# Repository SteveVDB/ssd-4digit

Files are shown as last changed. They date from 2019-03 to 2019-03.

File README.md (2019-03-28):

# DIY seven-segment display

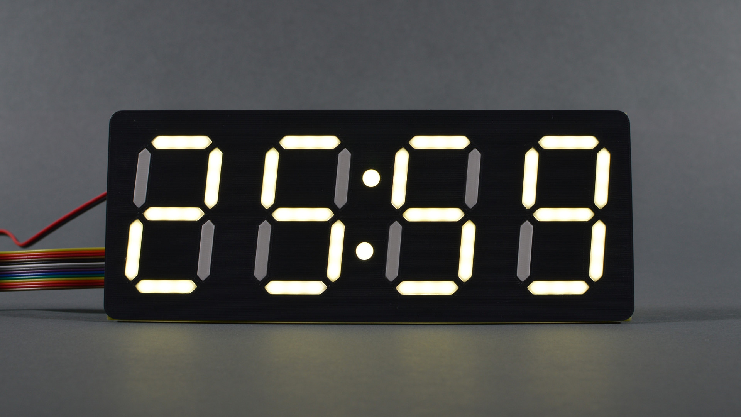
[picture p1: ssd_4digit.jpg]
DIY seven-segment display


## Hardware

* [schematic](/hardware/schematic): Contains the schematic with info and a BOM.
* [PCB](/hardware/pcb): Contains the PDF files to make the printed circuit
board.

## CAD

3D-models can be found [here](/cad). I've used gray PLA for the cover and white
PLA for the segments and the colon. To ensure that the segments and the colon
fit easily into the cover, you should scale them about 2% in the X- and
Y-direction.

## Demo

The [demo](/demo) folder includes a simple up/down counter (00:00 - 59:59) with
two selectable speeds: 1Hz and 10Hz. The code is written in VHDL, and uses this
[library](https://github.com/SteveVDB/VHDL).

See [video](https://www.youtube.com/watch?v=nK1kVYSnTY8) on YouTube.

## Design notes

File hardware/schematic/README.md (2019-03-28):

# Bill Of Material

All the components can be found on: [Digi-Key](https://www.digikey.com).

<table style="width:100%">
  <tr>
    <th>Item #</b></th>
    <th>Description</th>
    <th>Part number</th>
    <th>Reference</th>
    <th>Quantity</th>
  </tr>
  <tr>
    <td>1</td>
    <td>Resistor 120ohm 1% 0.125W 0805</td>
    <td>RC0805FR-07120RL</td>
    <td>R16..R22</td>
    <td>7</td>
  </tr>
  <tr>
    <td>2</td>
    <td>Resistor 270ohm 1% 0.125W 0805</td>
    <td>RC0805FR-07270RL</td>
    <td>R13</td>
    <td>1</td>
  </tr>
  <tr>
    <td>3</td>
    <td>Resistor 5k6ohm 1% 0.125W 0805</td>
    <td>RC0805FR-075K6L</td>
    <td>R1..12, R14, R15, R23..R36</td>
    <td>28</td>
  </tr>
  <tr>
    <td>4</td>
    <td>Electrolytic capacitor 68uF/25V SMD</td>
    <td>UCM1E680MCL1GS</td>
    <td>C1..C4</td>
    <td>4</td>
  </tr>
  <tr>
    <td>5</td>
    <td>PBLS2001D NPN/PNP transistor array TSOP6</td>
    <td>PBLS2001D,115</td>
    <td>Q1..Q4</td>
    <td>4</td>
  </tr>
  <tr>
    <td>6</td>
    <td>BC847B NPN transistor SOT-23</td>
    <td>BC847B,235</td>
    <td>Q5..Q12</td>
    <td>8</td>
  </tr>
  <tr>
    <td>7</td>
    <td>White led 6500K 2300mcd PLCC-2</td>
    <td>ASMT-UWB1-NX3B2</td>
    <td>D1..D86</td>
    <td>86</td>
  </tr>
  <tr>
    <td>8</td>
    <td>Connector header 14P 2.54mm SMD</td>
    <td>0015910140</td>
    <td>J2</td>
    <td>1</td>
  </tr>
  <tr>
    <td>9</td>
    <td>Connector header 2P 2.54mm THT</td>
    <td>640456-2</td>
    <td rowspan="3">J1</td>
    <td rowspan="3">1</td>
  </tr>
  <tr>
    <td>10</td>
    <td>Receptacle connector 2P</td>
    <td>3-640441-2</td>
  </tr>
  <tr>
    <td>11</td>
    <td>Connector cap, strain relief 2P</td>
    <td>643075-2</td>
  </tr>  
</table>

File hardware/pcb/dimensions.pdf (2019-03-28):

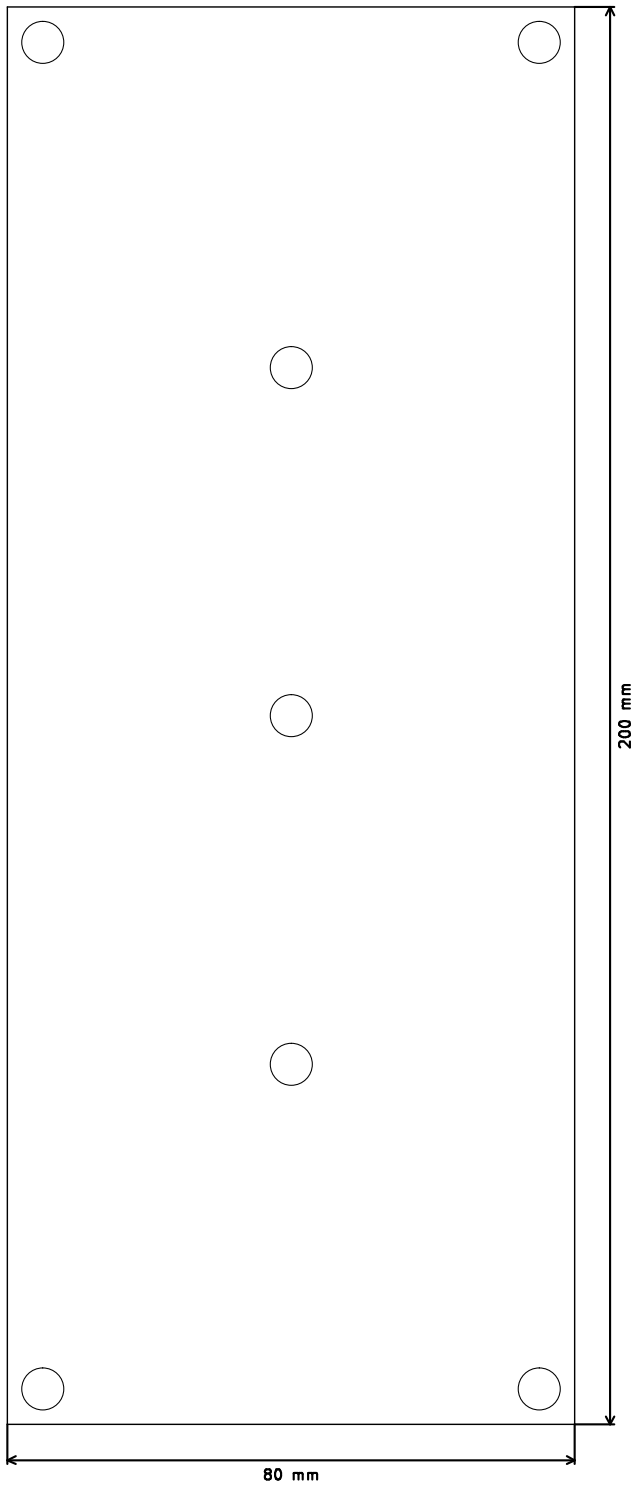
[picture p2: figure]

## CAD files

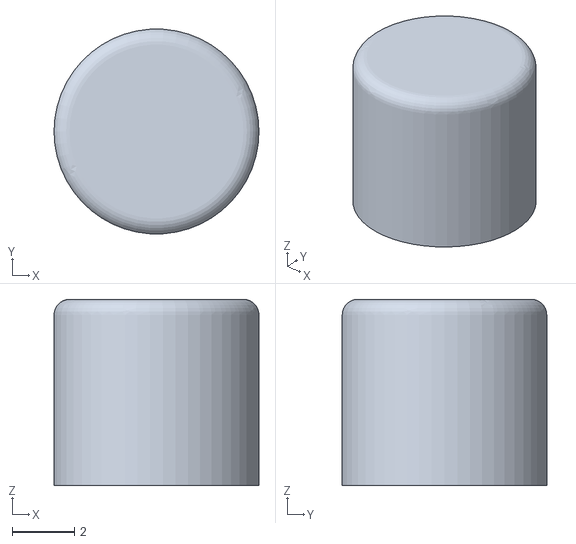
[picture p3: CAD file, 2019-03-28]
cad/colon.stl
6.60 x 6.59 x 6.00

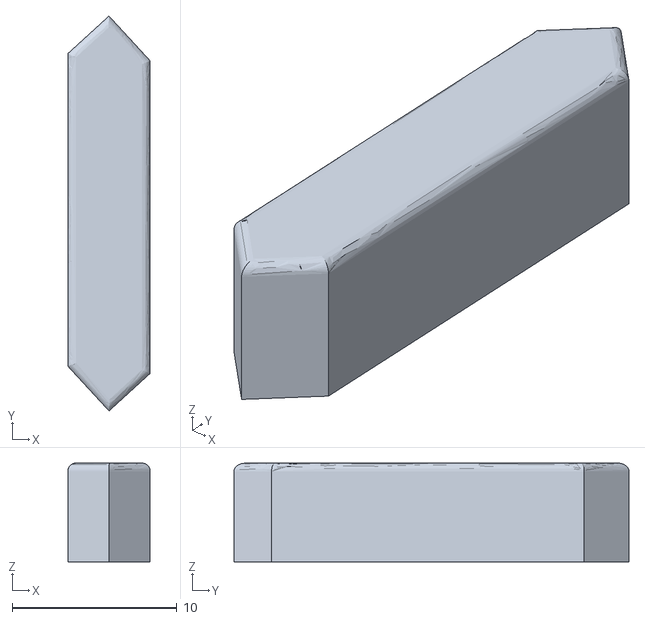
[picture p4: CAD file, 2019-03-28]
cad/segment_adg.stl
5.00 x 24.0 x 6.00

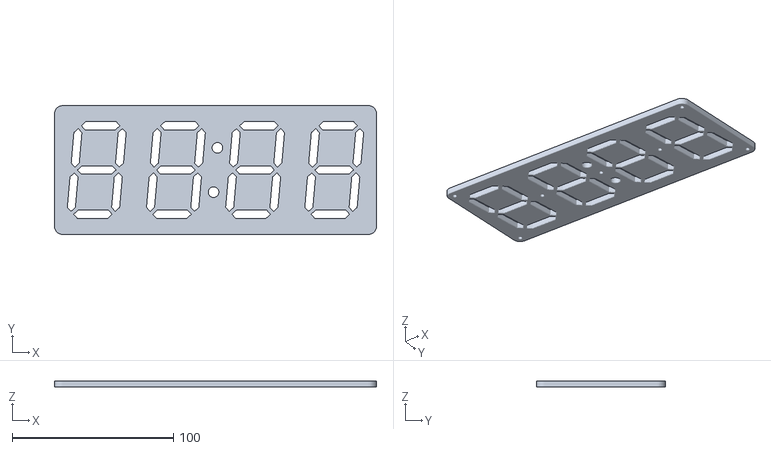
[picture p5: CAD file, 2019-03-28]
cad/cover.stl
200.0 x 80.0 x 4.00

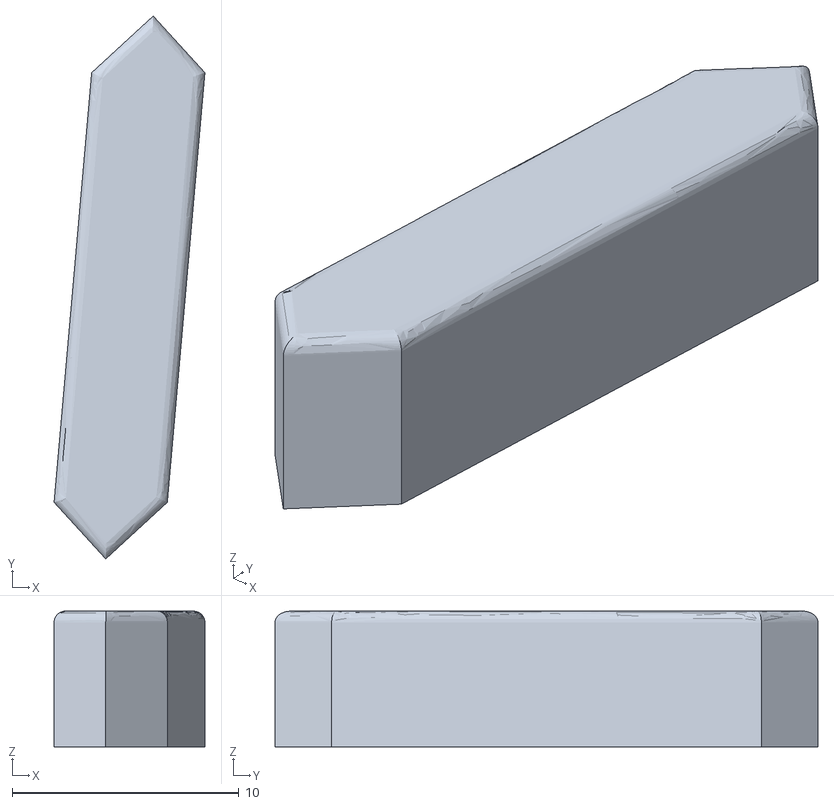
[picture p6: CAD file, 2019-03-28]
cad/segment_bcef.stl
6.66 x 24.0 x 6.00

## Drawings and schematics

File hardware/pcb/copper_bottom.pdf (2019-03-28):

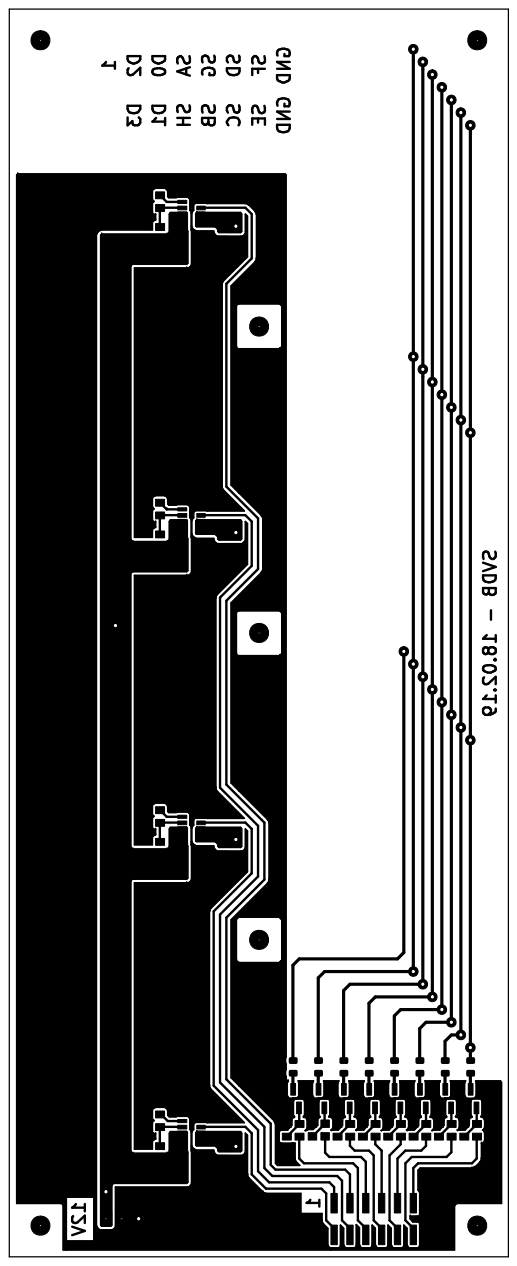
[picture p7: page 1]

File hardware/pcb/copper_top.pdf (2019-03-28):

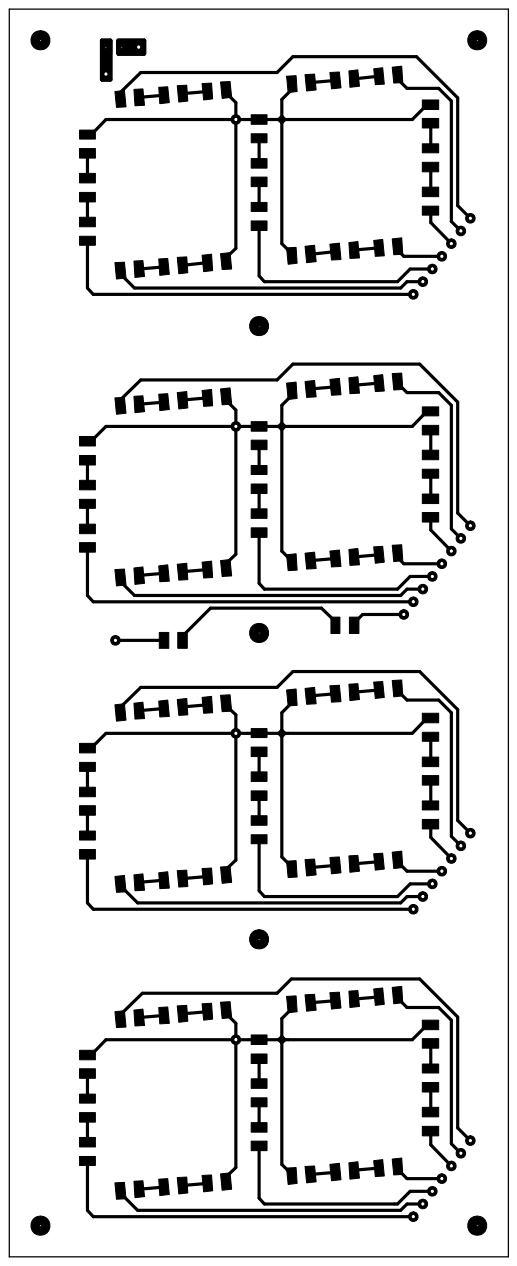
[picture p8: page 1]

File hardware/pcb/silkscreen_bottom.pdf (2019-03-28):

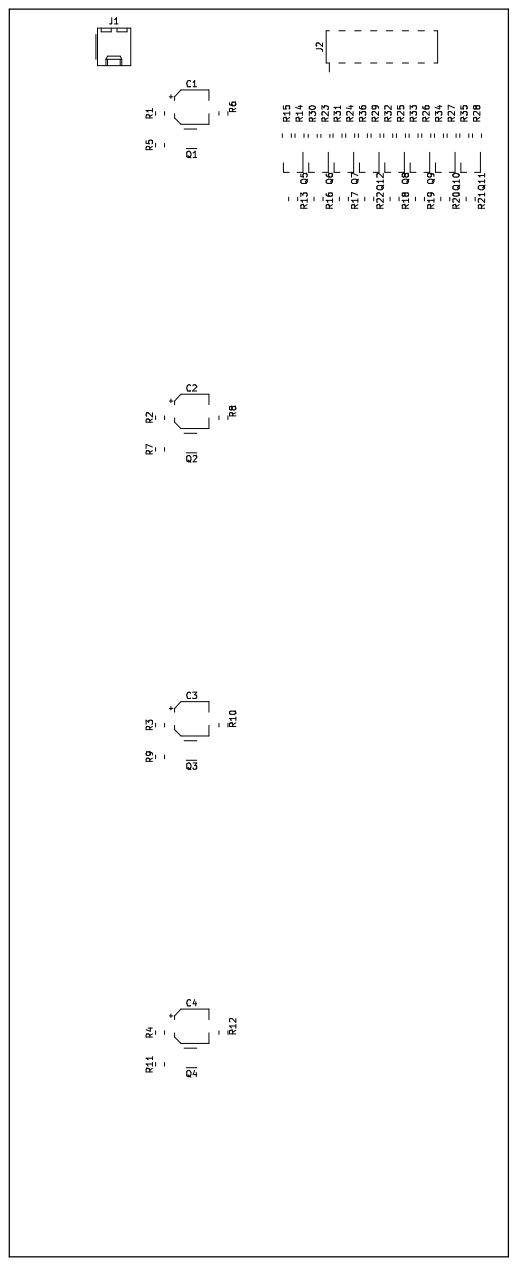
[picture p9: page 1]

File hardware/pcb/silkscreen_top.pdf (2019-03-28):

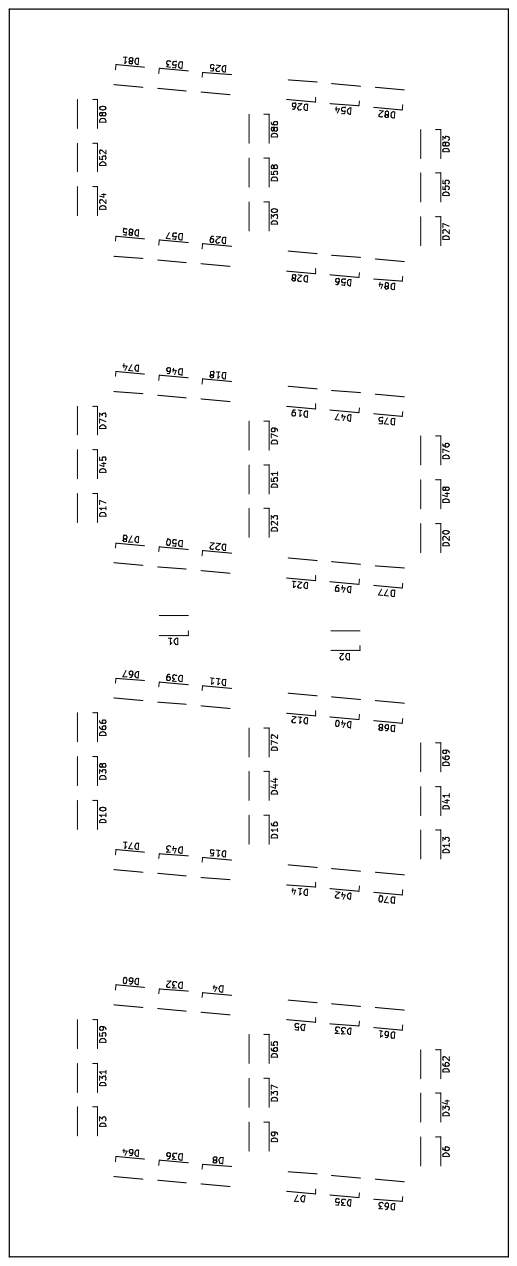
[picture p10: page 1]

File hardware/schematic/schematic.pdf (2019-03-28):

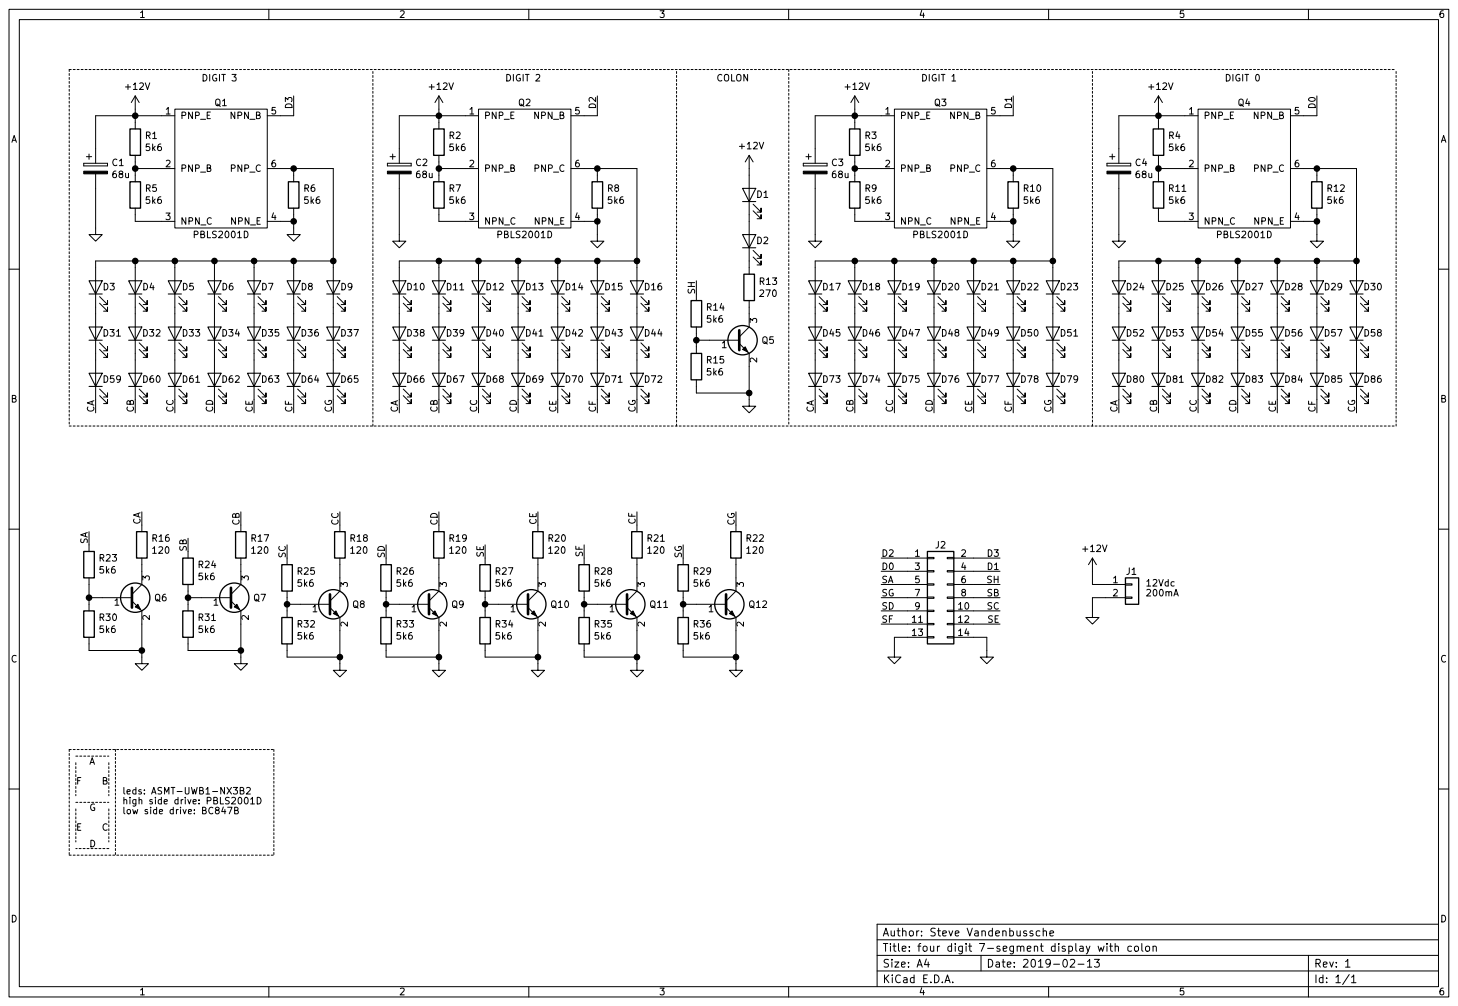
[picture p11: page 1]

Id: 1/1 Title: four digit 7-segment display with colon Author: Steve Vandenbussche
